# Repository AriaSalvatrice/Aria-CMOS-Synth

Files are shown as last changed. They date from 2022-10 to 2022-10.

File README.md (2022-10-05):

# Aria Salvatrice's WIP CMOS Synth

This repository aims to document the Lunetta-style modular CMOS synth I'm building to learn more about electronics. 

Wanna see it in action?

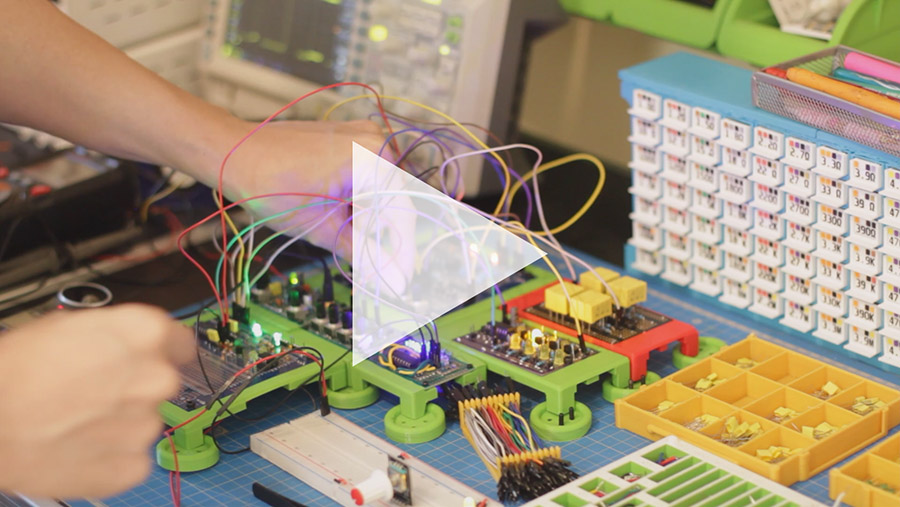
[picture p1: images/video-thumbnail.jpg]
Video Thumbnail (https://youtu.be/UeoF3UkMkqE)


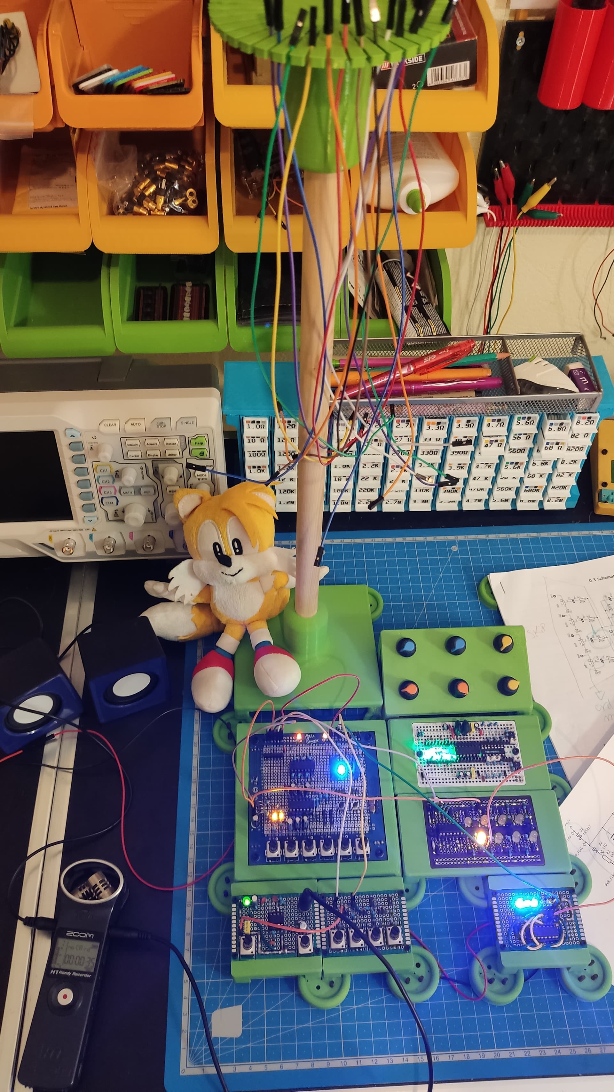
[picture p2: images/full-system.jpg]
Overall view of a system with a few modules


For now, this stuff is only provided publicly to solicit feedback. Depending on the quality of the completed synth and community interest, maybe I'll turn it into a proper open hardware project fit for human consumption one day. But for now, nobody should reproduce those builds, nor even attempt to learn something from them. I literally didn't know how to make a LED emit light rather than smoke at the start of 2022. I have no clue what I'm doing.

Software you need to open the source files I'm sharing:
- Schematics use [KiCad](https://www.kicad.org/) 6.99+
- Layouts use [DIY Layout Creator](http://diy-fever.com/software/diylc/)
- 3D prints use [FreeCAD](https://www.freecadweb.org/)

Other than this file repository, I document my build process [in a thread on the Look Mum No Computer forum](https://lookmumnocomputer.discourse.group/t/starting-a-little-cmos-synth-build/5375/), post the infrequent video [on my Youtube](https://www.youtube.com/c/AriaSalvatrice), sometimes lurk [/r/synthdiy](https://old.reddit.com/r/synthdiy/), and spam [excessively detailed updates in between the gay shitposts on my personal Tweeter that nobody should follow](https://twitter.com/AriaSalvatrice). 

## About Lunetta and CMOS synths

CMOS synths primarily focus primarily on exploring the interactions of the CMOS 4000 series of chips, which deal with digital logic, signals that are either high or low. Compared to more advanced synth DIY endeavors, they are rather easy to build and understand, cheap to make, and reward experimentation. They are sometimes named after [Stanley Lunetta](http://moosack.net/), who pioneered this style of circuit, and called his work _sound sculptures_. 

Your best introduction to musical applications of CMOS chips would be [Elliot Williams' Logic Noise series](https://hackaday.com/series_of_posts/logic-noise/). To dig deeper, explore over a decade of archives in the [Lunetta forums on electro-music.com](https://electro-music.com/forum/forum-160.html), and read the in-depth circuit analyses of the [Castle Rocktronics](http://castlerocktronics.com/modular.html) modules. 

## Design Goals

Mostly learning electronics for myself, and ending up with a neat little rhythm machine, for now. But it'd be cool if I could eventually turn the best circuits into multiple dedicated PCBs, that you could wire up either with pin headers, or cables going to banana jacks on a panel for a more traditional Lunetta setup.

## Electrical Design

All the guts of the synth are exposed as bare PCBs with male header pins, that the performer patches with female DuPont cables. The small size makes it unsuited for live patching, but exceptionally well suited to experimentation with breadboards.

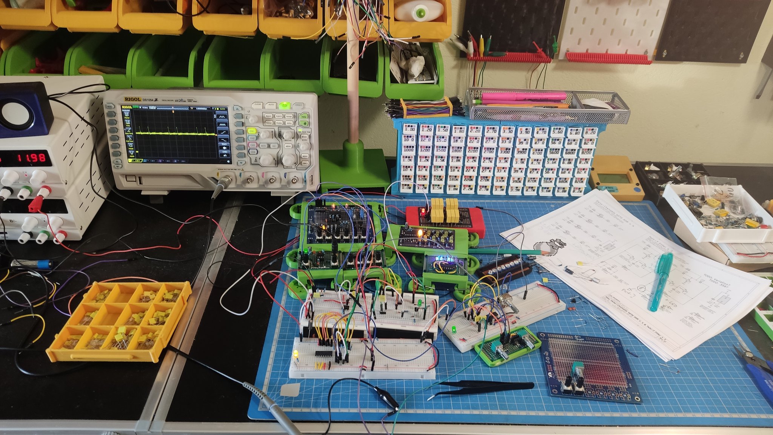
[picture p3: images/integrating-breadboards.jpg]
Extending the system with breadboards


As there are no panels, the aesthetics of the PCBs are important. When performing on video, they must provide a fun and colorful visual spectacle with mucho Blinkenlichten. They must also double as a reasonably ergonomic user interface.

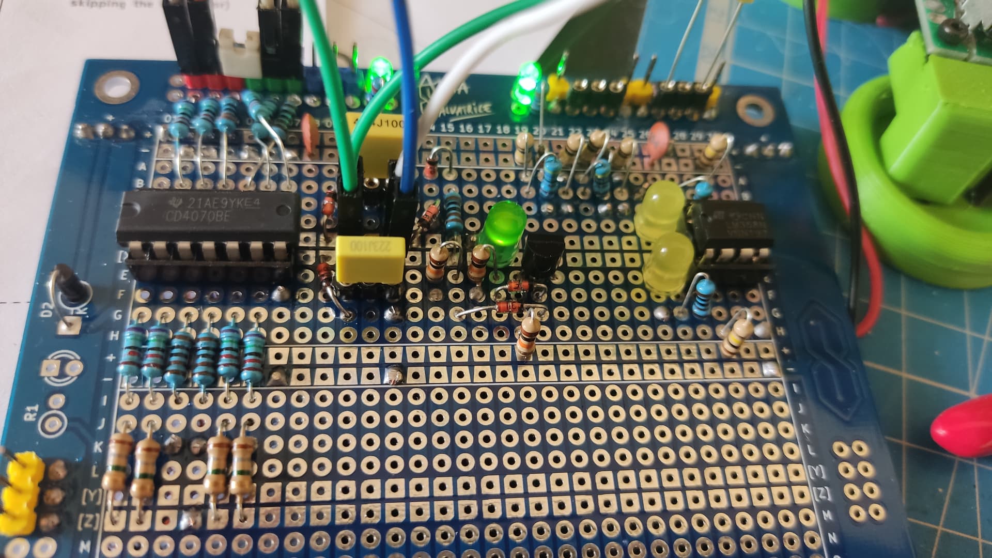
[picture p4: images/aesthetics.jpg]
The aesthetics of the build are important


The system runs on +12V DC. It will also work on +9V, but the values are tuned for +12V, so pitches and envelopes are different at +9V. Some of the circuits I made no longer seem to work at +5V. I picked +12V to make it easier to integrate to a modular synth in the future. There is no dedicated power module yet, it runs off a bench PSU.

To keep the patches readable for the performer, most of the hardwiring is run below the boards. 

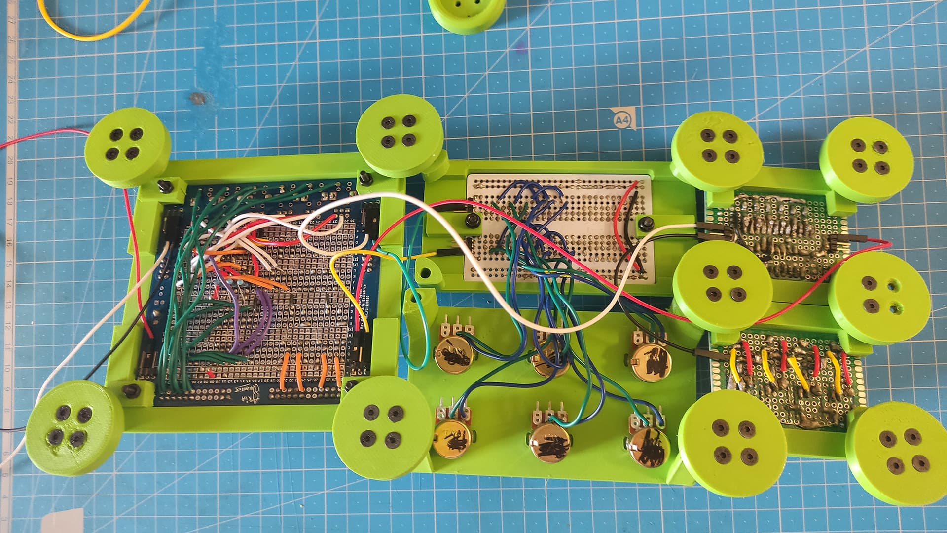
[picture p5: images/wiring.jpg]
Wiring


Most of the circuits used were designed by much more competent people and shared under permissive terms. Individual credits are provided for each module. If you want to learn, learn from the originals, not from my stuff.

## Mechanical Design

The modules are currently printed with PLA. The models were made with FreeCAD. As I don't know FreeCAD well, they are not as easy to modify as I like and can require some post-processing in Blender, the main value of the FreeCAD project is to have a set of measurements that works pretty well. 

The modules tile to an approximate 60×60mm grid. This allows integrating 100×100mm PCBs in 120×120mm modules comfortably, the maximum size for which some PCB fab houses cut you a special deal for minimum quantity orders.

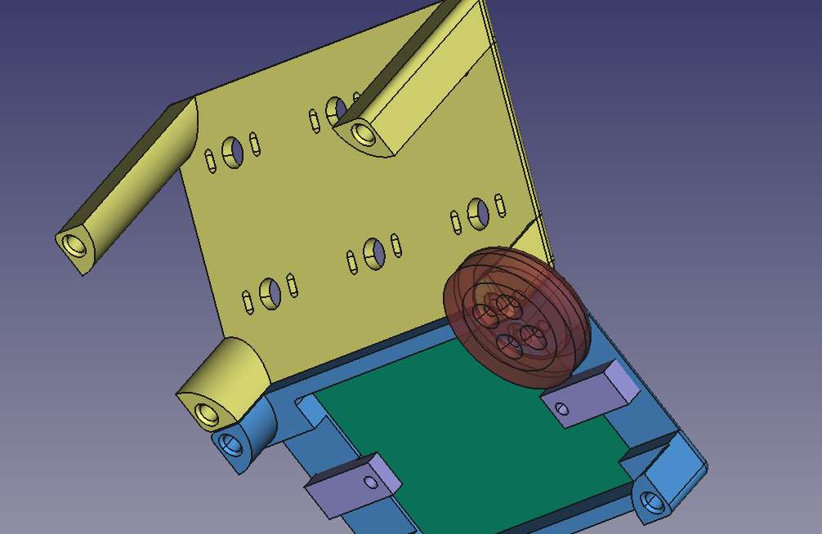
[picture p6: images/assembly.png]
Assembly of modules


The modules are held together by their feet with little holding rings that look like buttons, taking countersunk screws. The holes in the feet of modules are reinforced with heat set inserts.

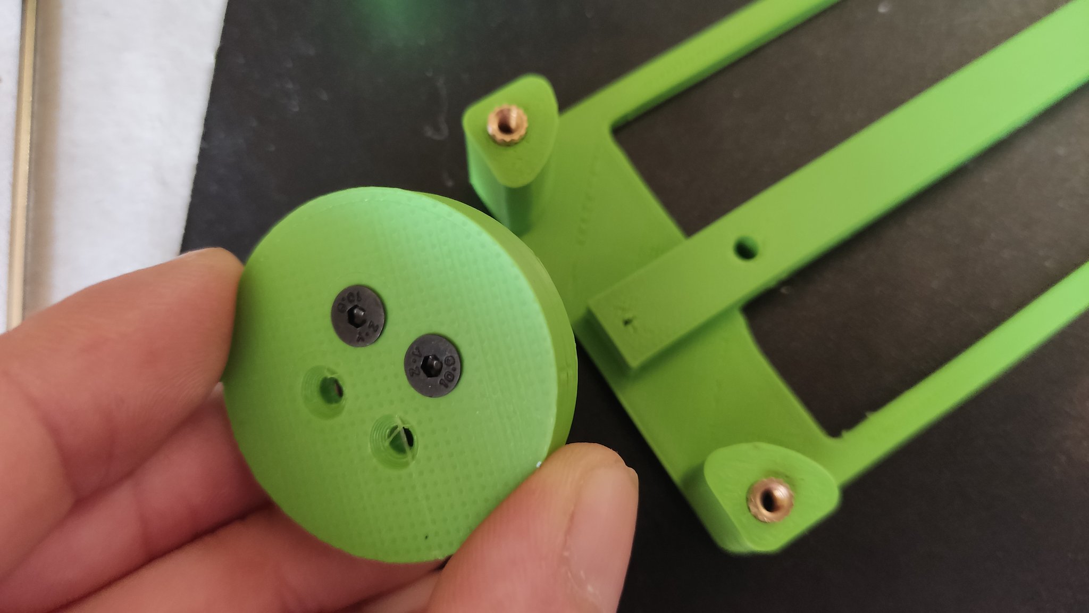
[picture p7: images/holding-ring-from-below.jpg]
Holding ring from below


The models should not require a particularly well tuned printer to make. Most can be printed without supports and don't require much post-processing.

Here's the main measurements (will add more as I confirm them precisely):

| Dimension Name | Value | Comments |
|---|---|---|
| Grid size | 60 × 60 mm 
| Height of modules | 18 mm | Tall enough for vertical headers below the boards, but angled are preferred.
| Spacing between modules | 0.8 mm | Currently, 120×120mm modules don't account for this properly.

## Licensing

lol

-----------

Thanxx for peeping my project. Feel free to look at my learning process, but do not treat my schematics and layouts as instructions yielding an usable product.

Send me thoughts and dog gifs to <woof@aria.dog>.

ttyl,

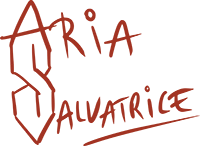
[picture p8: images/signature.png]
Aria Salvatrice


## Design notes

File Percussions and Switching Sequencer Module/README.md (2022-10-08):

Percussions Module & Switching Sequencer Rev1
---------------------------------------------

4 circuits here, meant for my custom prototype board:
- Daisy-chainable XOR. Due to a mistake in the Rev 1 of my protoboard, not all the I/O is at the top, the 4th channel is on the side instead. 
- "Hi-Hat" Envelope with "Choke". Inspired by a circuit [from the Logic Noise series](https://hackaday.com/2015/04/10/logic-noise-more-cmos-cowbell/), just don't ask me how it works, I came up with it through experimentation.
- Gate to Trigger circuit based on Ken Stone's [CGS 24](https://sdiy.info/wiki/CGS_gate_to_trigger_converter). While I got it to work on breadboard, **I couldn't get my final build to work, and didn't manage to diagnose it yet**, so I don't know for sure whether my build or my layout is wrong. 
- Switching sequencer with oscillator, based on [Logic Noise](https://hackaday.com/2015/02/23/logic-noise-the-switching-sequencer/). Uses only 2 gate inputs and 4 pots, but the chip could support 3 and 8.

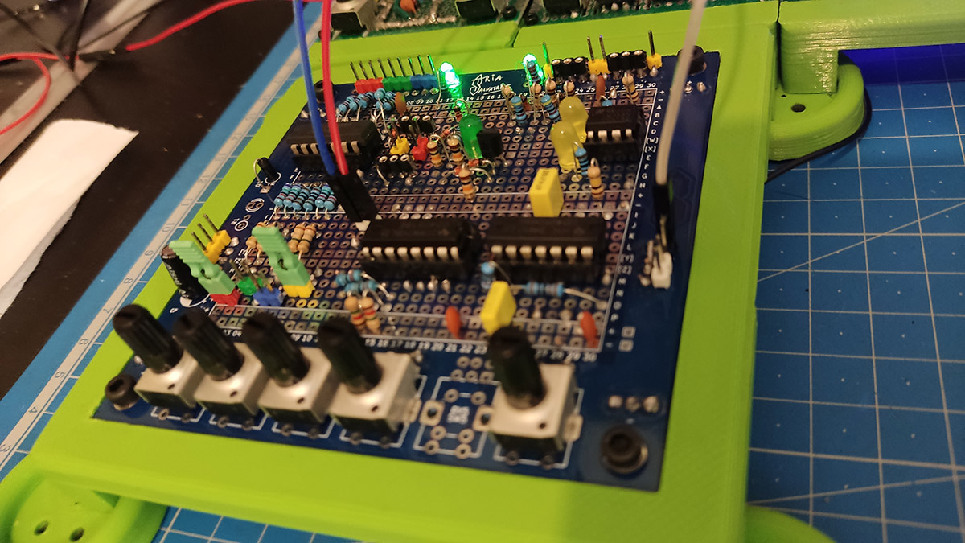
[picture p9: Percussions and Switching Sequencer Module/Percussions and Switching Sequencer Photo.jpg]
Photo of the module


------

_This repository documents my learning process. I advise against building those circuits or learning from them. See the [main README file](../README.md) for more information._

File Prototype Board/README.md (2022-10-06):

Protoboard Rev2B
----------------

Inspired by commercialy available Permanent Prototype boards, and [Analog Output's Protoboard for Eurorack and Kosmo](https://github.com/holmesrichards/Protoboard). It's 99×99 mm, to get the best deal from PCB fab houses.

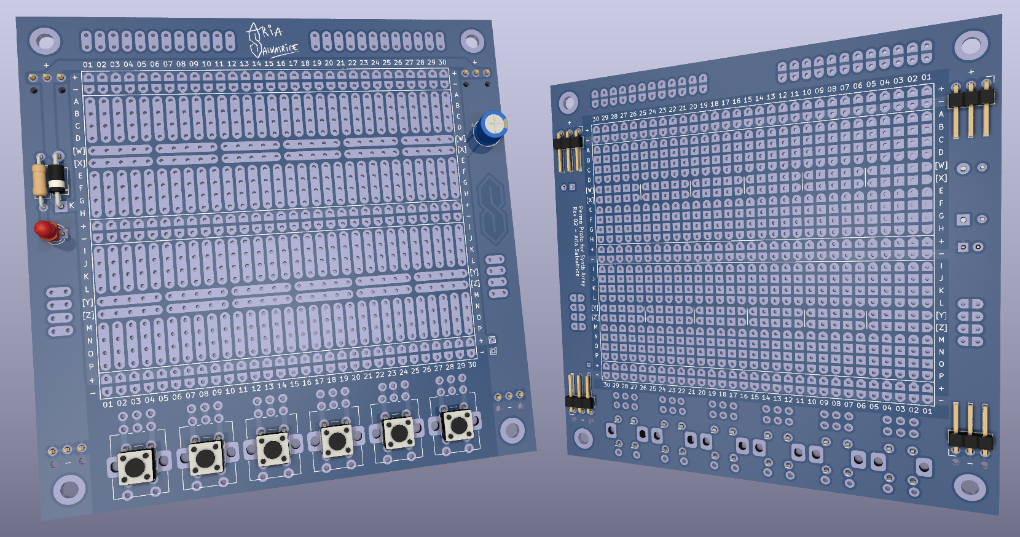
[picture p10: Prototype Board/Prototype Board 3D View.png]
3D view


There's built-in reverse voltage protection, a status LED, a main decoupling capacitor, room for 6 potentiometers or tactile buttons, and two half-breadboard layouts stacked over each other, with power rails.

The footprints at the bottom can be populated with pushbuttons or potentiometers. They are not connected to the rest of the circuit, but the topmost pad of each group can be used to run wires. Bear in mind that potentiometers are mounted with the pins in reverse order.

The 2 groups of 12 pins at the top and 2 groups of 4 pins on the sides are not connected to anything either. Use them creatively, for example for I/O.

The [W], [X], [Y] and [Z] rows are comprised of 6 groups of 5 pads each, which could be useful to run a signal below a chip.

Those boards are for a single rail power supply, limiting their usefulness for most synthesizer projects.

These are the files for Rev2B. Rev2A has been sent to fabricate (will update). Rev2B is the same with a minor correction (misaligned tracks) and has not been tested.

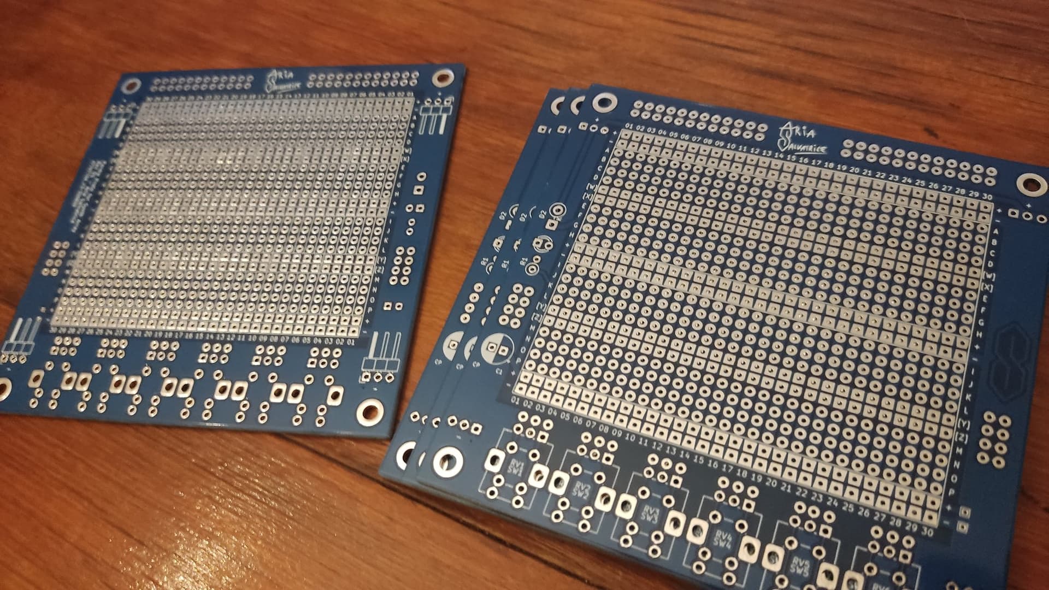
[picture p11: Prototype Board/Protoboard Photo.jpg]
Photo of the module


This is a picture of Rev1, which has a few flaws (such as the status LED shorting if populated). It was my first PCB ever, so I'm happy it even worked at all.

------

_This repository documents my learning process. I advise against building those circuits or learning from them. See the [main README file](../README.md) for more information._

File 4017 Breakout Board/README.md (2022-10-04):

4017 Breakout Board Rev1
------------------------

8-step counter.

[Based on the Logic Noise series](https://hackaday.com/2015/04/24/logic-noise-sequencing-in-silicon/). The article suggests using two 4017 to drive LEDs, but this design uses transistors instead. Seems to work fine. Layout built for a breadboard-style PCB. Harwired reset to limit it to 8 steps, which is more useful in conventional music than the chip's maximum of 10.

This revised layout was not double-checked against the working original build (as I altered the layout a bit on the fly while building).

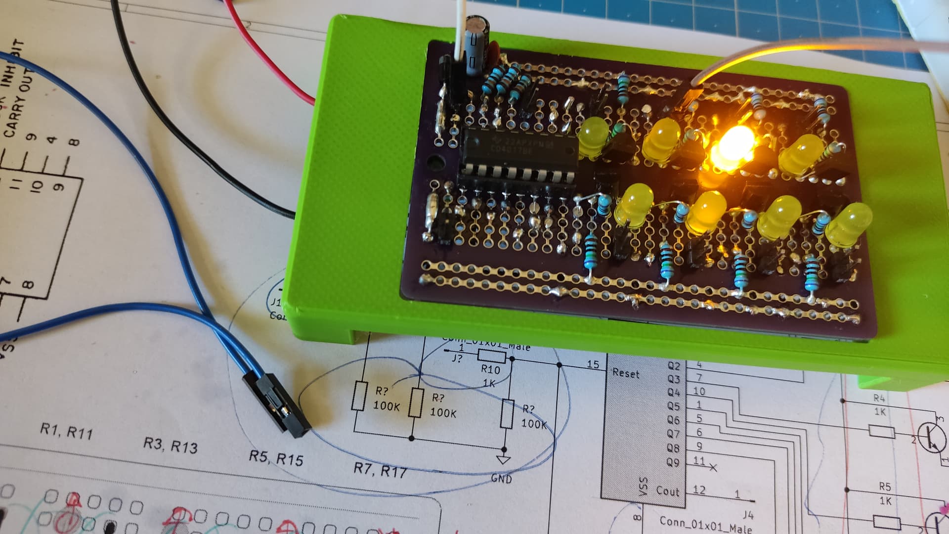
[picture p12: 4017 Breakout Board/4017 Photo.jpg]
Photo of the module


------

_This repository documents my learning process. I advise against building those circuits or learning from them. See the [main README file](../README.md) for more information._

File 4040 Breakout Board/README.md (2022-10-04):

4040 Breakout Board Rev1
------------------------

The 4040 binary counter can be used to divide a clock or to generate sub-oscillators.

[Based on the Logic Noise series](https://hackaday.com/2015/02/17/logic-noise-8-bits-of-glorious-sounds/). Layout meant for a 40×60 mm perfboard. No schematic was made for that one, but it's really simple. It drives LEDs directly, which might be a terrible idea, I have not really checked (it works tho). I routed the cables above the chip, which was a terrible idea. Also, the angled headers do not have sufficient lateral clearance as indicated, I had to bend them to be vertical instead.

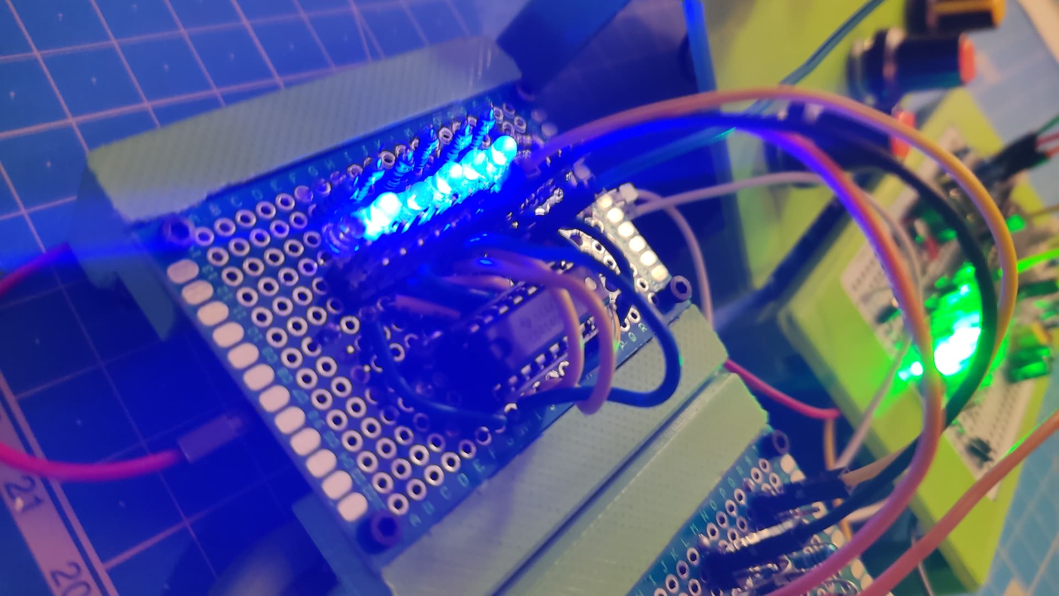
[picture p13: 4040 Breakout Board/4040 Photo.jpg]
Photo of the module


------

_This repository documents my learning process. I advise against building those circuits or learning from them. See the [main README file](../README.md) for more information._

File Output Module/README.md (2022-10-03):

Output Module Rev1
------------------

Based on the [Castle Rocktronics schematics](http://castlerocktronics.com/modular/articles/CR-002_-_Output_Mixer.pdf). Like it's basically a copy-paste at this point. Using a TL072 that is almost certainly not authentic. You'll need to amplify the signal to listen to it comfortably (the original schematics suggest a way to do it, but I haven't bothered).

Built for a 60×40 mm perfboard, drilled to fit a mini-jack, with grooves for the potentiometer routed out using a rotary tool with a cutoff wheel. Wear a respirator while machining a PCB!

I made the mixer separately. Its design has a fatal flaw so I will not bother to document it.

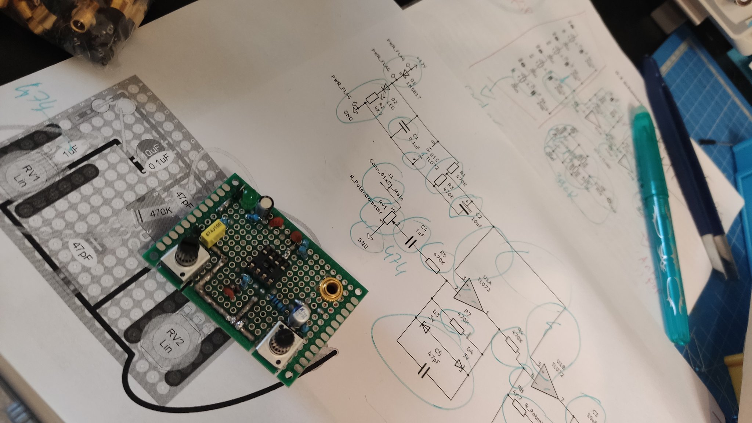
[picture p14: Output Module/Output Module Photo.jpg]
Photo of the module


------

_This repository documents my learning process. I advise against building those circuits or learning from them. See the [main README file](../README.md) for more information._

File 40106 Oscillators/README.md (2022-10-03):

40106 Oscillators Rev2
----------------------

Six voltage-controlled oscillators, 2 LFO, 2 in the lower audio range, and 2 in the higher audio range. Square and triangle wave outputs. 

This build is meant to use my Perma-Proto PCBs Rev1. 

The oscillators are [based on the Logic Noise series](https://hackaday.com/2015/03/09/logic-noise-sawing-away-with-analog-waveforms/). The [schematics from Castle Rocktronics were also used](http://castlerocktronics.com/modular/articles/CR-001_-_4xSQUARE.pdf). It's worth noting that when using all inverters on a 40106, they will have a fairly noticeable amount of cross-talk.

To fill the space, there are also passive mults, LDRs, pushbuttons, and a pair of vactrol LPG, I cribbed [the schematics from Mystic Circuits](https://github.com/mysticcircuits/0HP_Modular/tree/master/Hardware/0HP%20Vactrol%20LPG-VCA). The vactrols are handmade with a LDR and a LED in heat shrink tubing. They need decent current to work, not everything in my system manages to ping them properly, so I wanna remake that part better later.

While the Rev Log pots specified will yield better results, I used Linear, not having anything else in stock.

I made a Rev 1 of it previously, but it's too flawed to bother documenting.

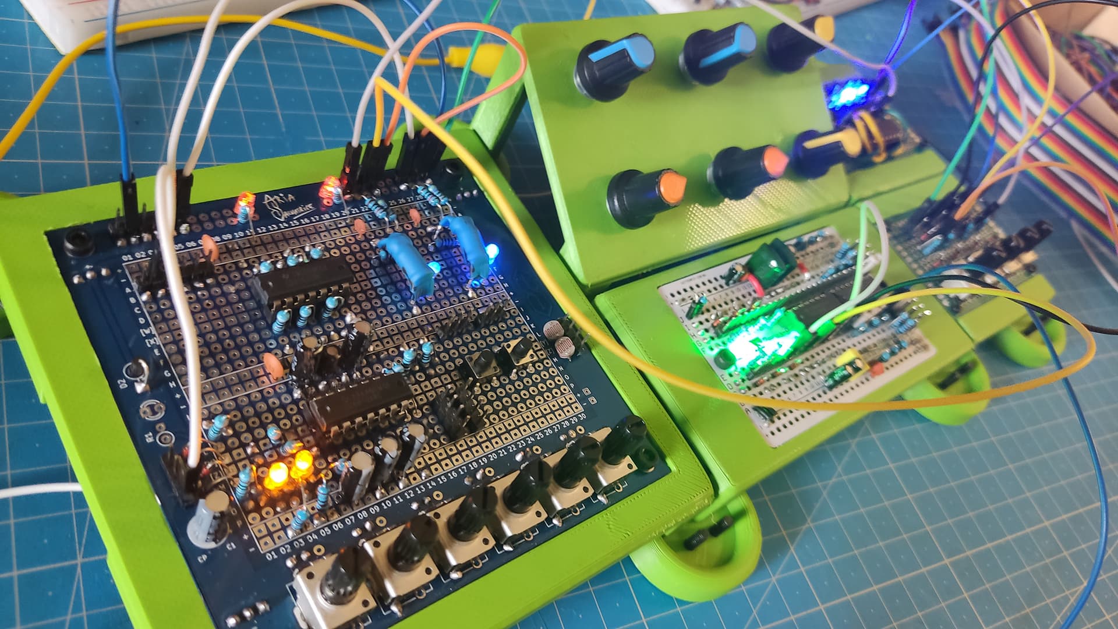
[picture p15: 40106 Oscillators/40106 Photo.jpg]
Photo of the module
    
Rev 2 on the left, Rev 1 immediately to its right.

------

_This repository documents my learning process. I advise against building those circuits or learning from them. See the [main README file](../README.md) for more information._

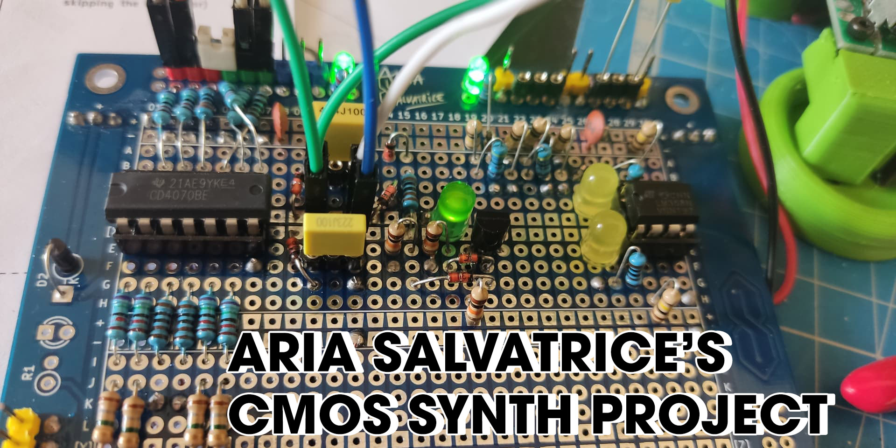
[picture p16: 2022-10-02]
images/header.jpg

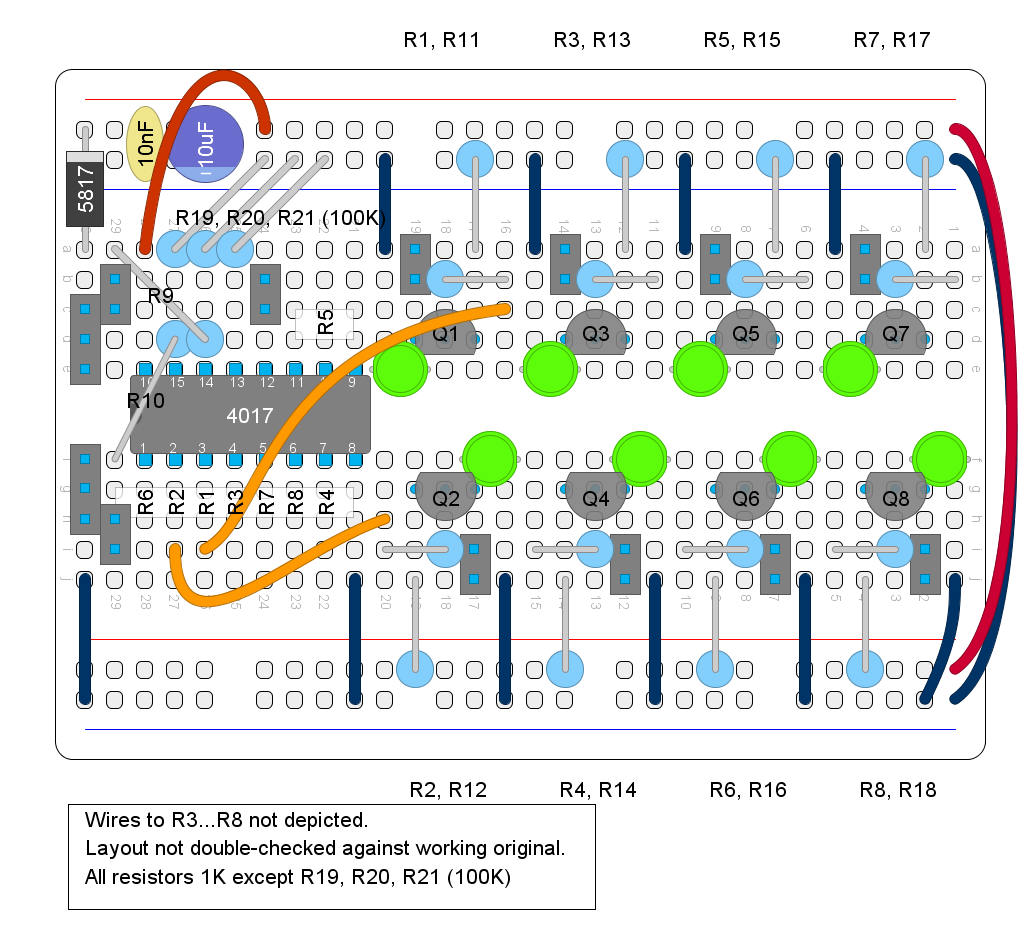
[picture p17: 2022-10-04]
4017 Breakout Board/4017 Layout.png

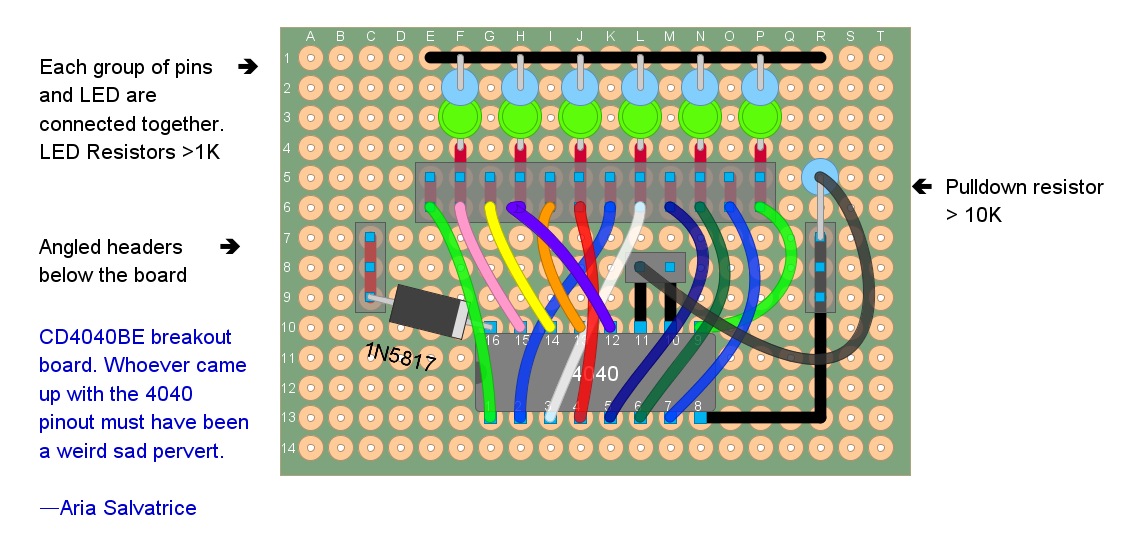
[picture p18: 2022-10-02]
4040 Breakout Board/4040 Layout.png

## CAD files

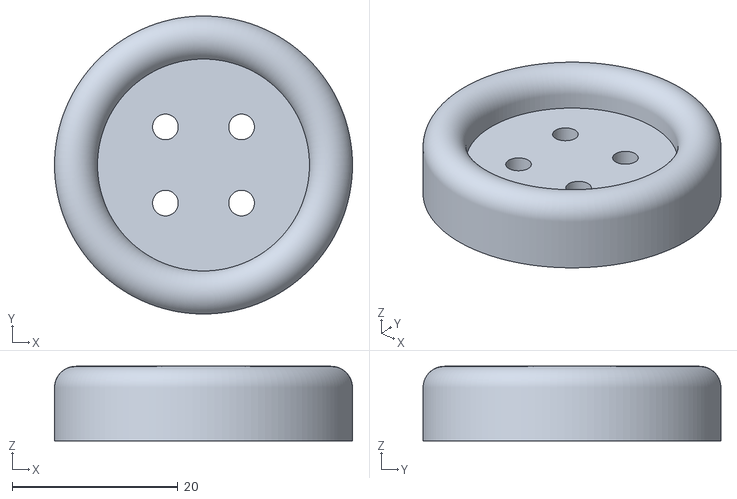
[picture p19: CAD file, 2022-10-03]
3D Prints/stl/Holding Ring.stl
36.0 x 36.0 x 9.00

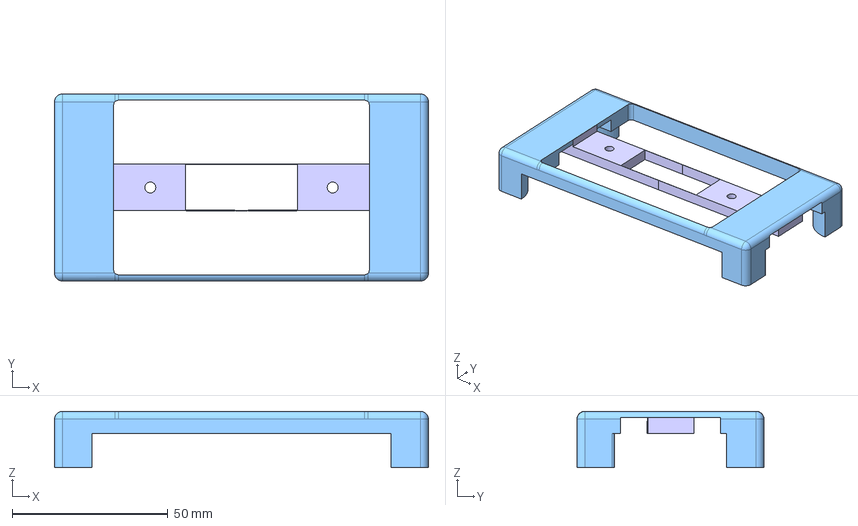
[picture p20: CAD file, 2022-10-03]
3D Prints/Synth Support System.FCStd
120.0 x 60.0 x 18.0 mm
Box Holder Center Holes L
Box Holder Center Hole R

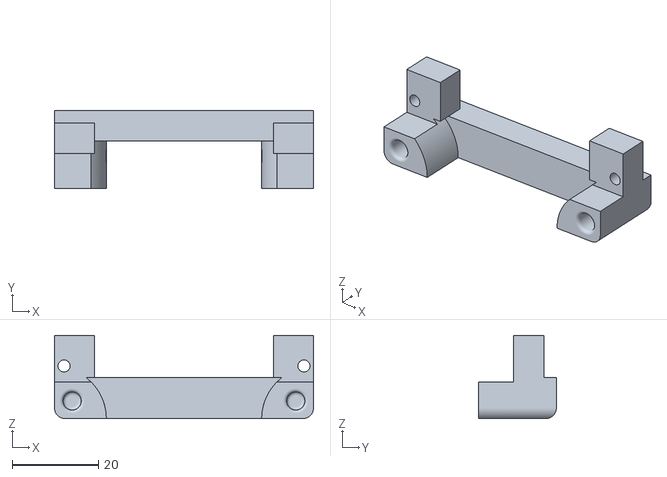
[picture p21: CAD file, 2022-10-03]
3D Prints/stl/Support - 40x60 perfboard - single support.stl
60.0 x 18.0 x 19.3

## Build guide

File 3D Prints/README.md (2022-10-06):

3D Prints
---------
The system tiles pretty well, but can use a tiny bit of postprocessing help: a heat gun, 3D pen, and deburring tool can help obtain a better fit.

The feet of supports require M3 heat set inserts. A soldering iron is required to install them, only use an old tip you don't mind ruining.

Adding the rest of the files as I double-check the versions, dimensions, and make test prints.

### `Synth Support System.FCStd`

A messy and exploratory file, as I don't know FreeCAD much yet. Still, might be useful to make variations, try out changing dimensions in the spreadsheet and see if it works. Be ready to double-check dimensions and post-process models in Blender if you use it.

### `./stl/Holding Ring.stl`

Hold feet together. Takes countersunk M3×12mm screws.

### `./stl/Support - 60x40 perfboard - single support.stl`

[UNVERIFIED MODEL] Print two per 40×60 mm perfboard. In the default orientation, where it is printed on its side, it requires no supports. 

For a smoother surface finish, it can alternatively be printed upside-down with small painted-on supports at the edge of PCB holder, as follows:

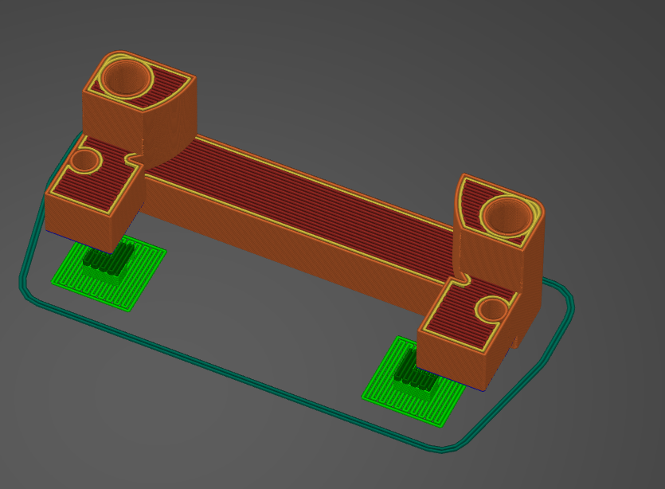
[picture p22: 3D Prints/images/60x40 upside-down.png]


Secure boards with M2x12 screws and nuts. Note that two contiguous perfboards will almost touch, pads to their sides might be at risk of shorting if used.

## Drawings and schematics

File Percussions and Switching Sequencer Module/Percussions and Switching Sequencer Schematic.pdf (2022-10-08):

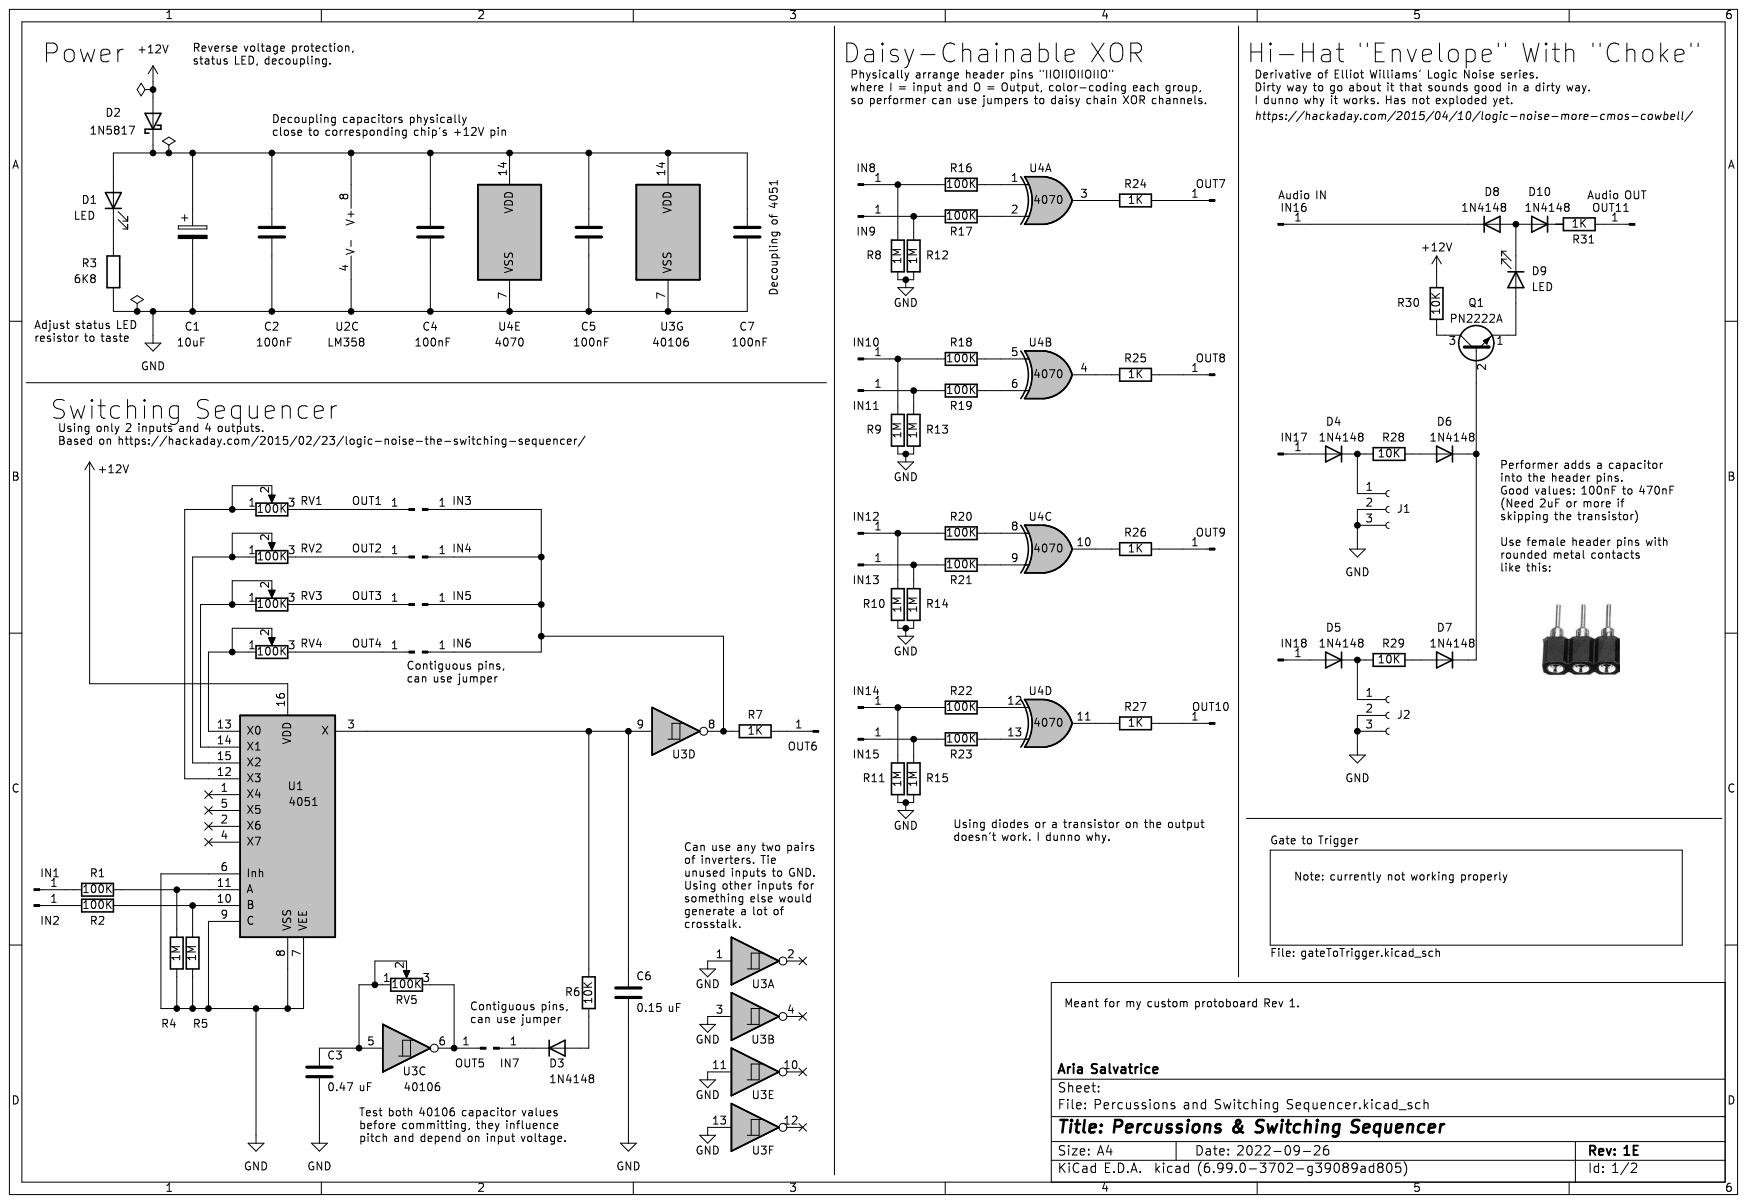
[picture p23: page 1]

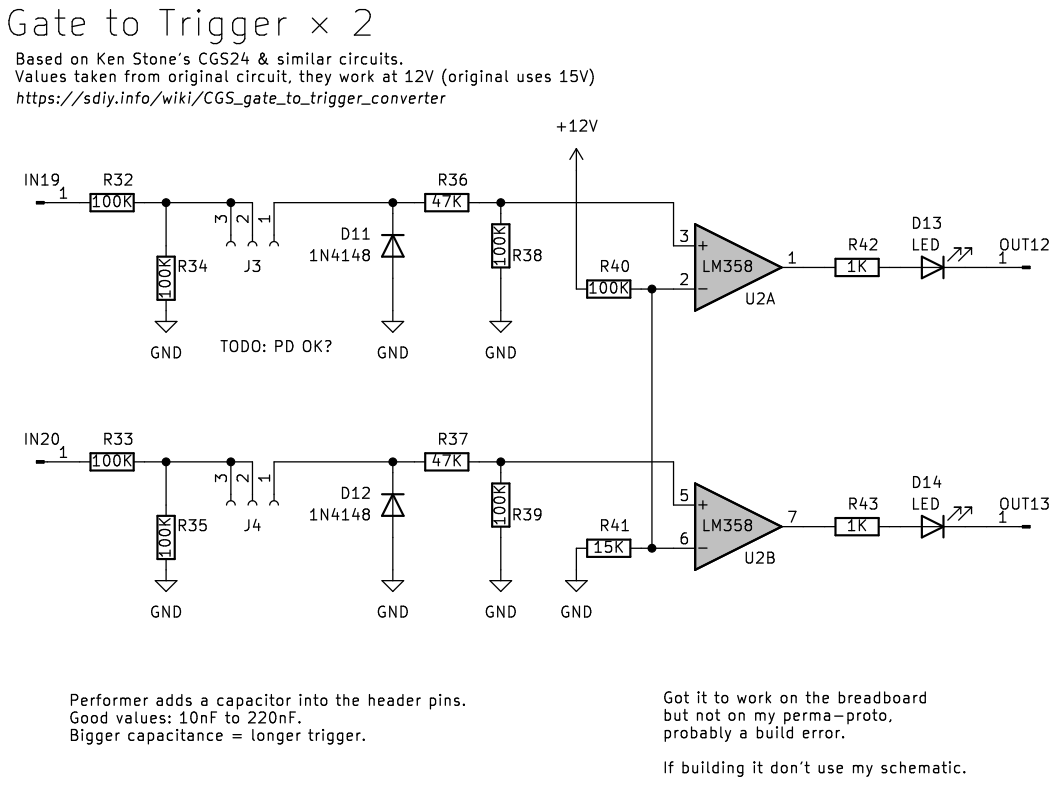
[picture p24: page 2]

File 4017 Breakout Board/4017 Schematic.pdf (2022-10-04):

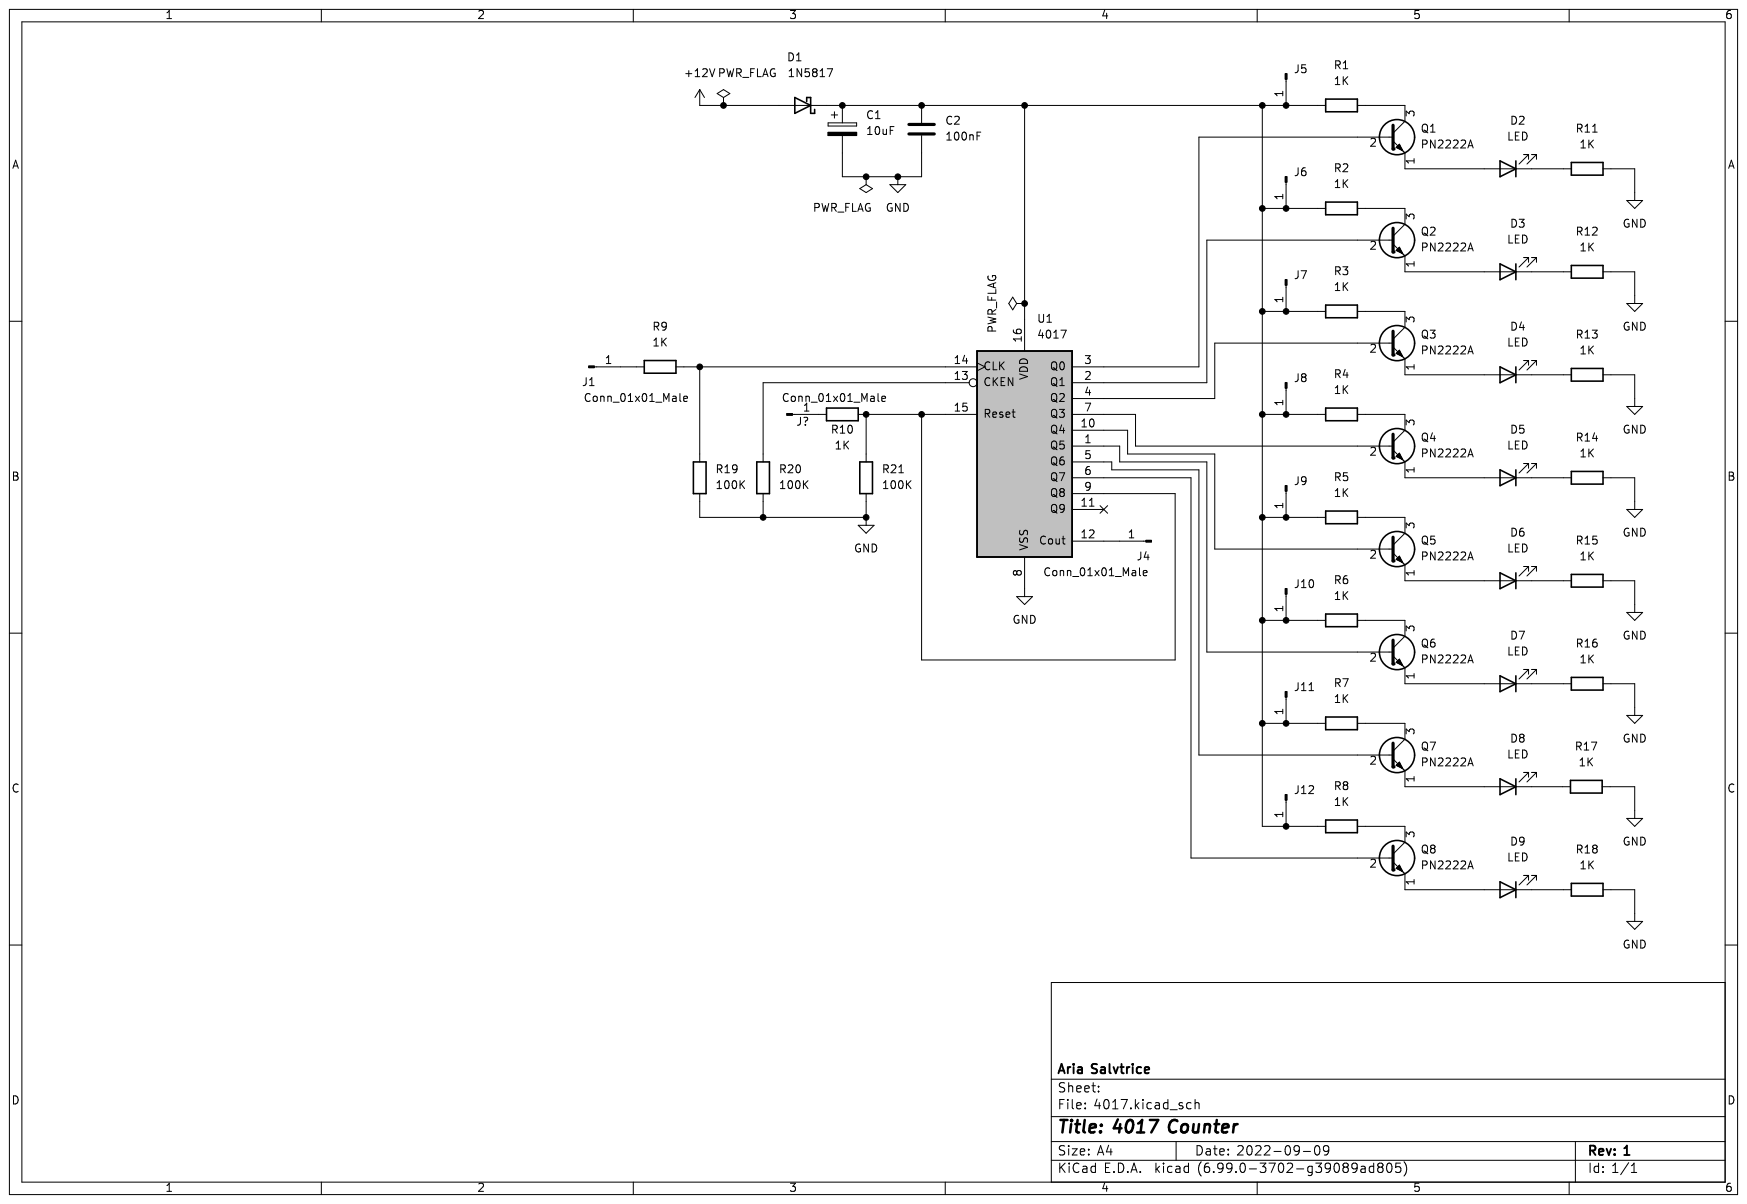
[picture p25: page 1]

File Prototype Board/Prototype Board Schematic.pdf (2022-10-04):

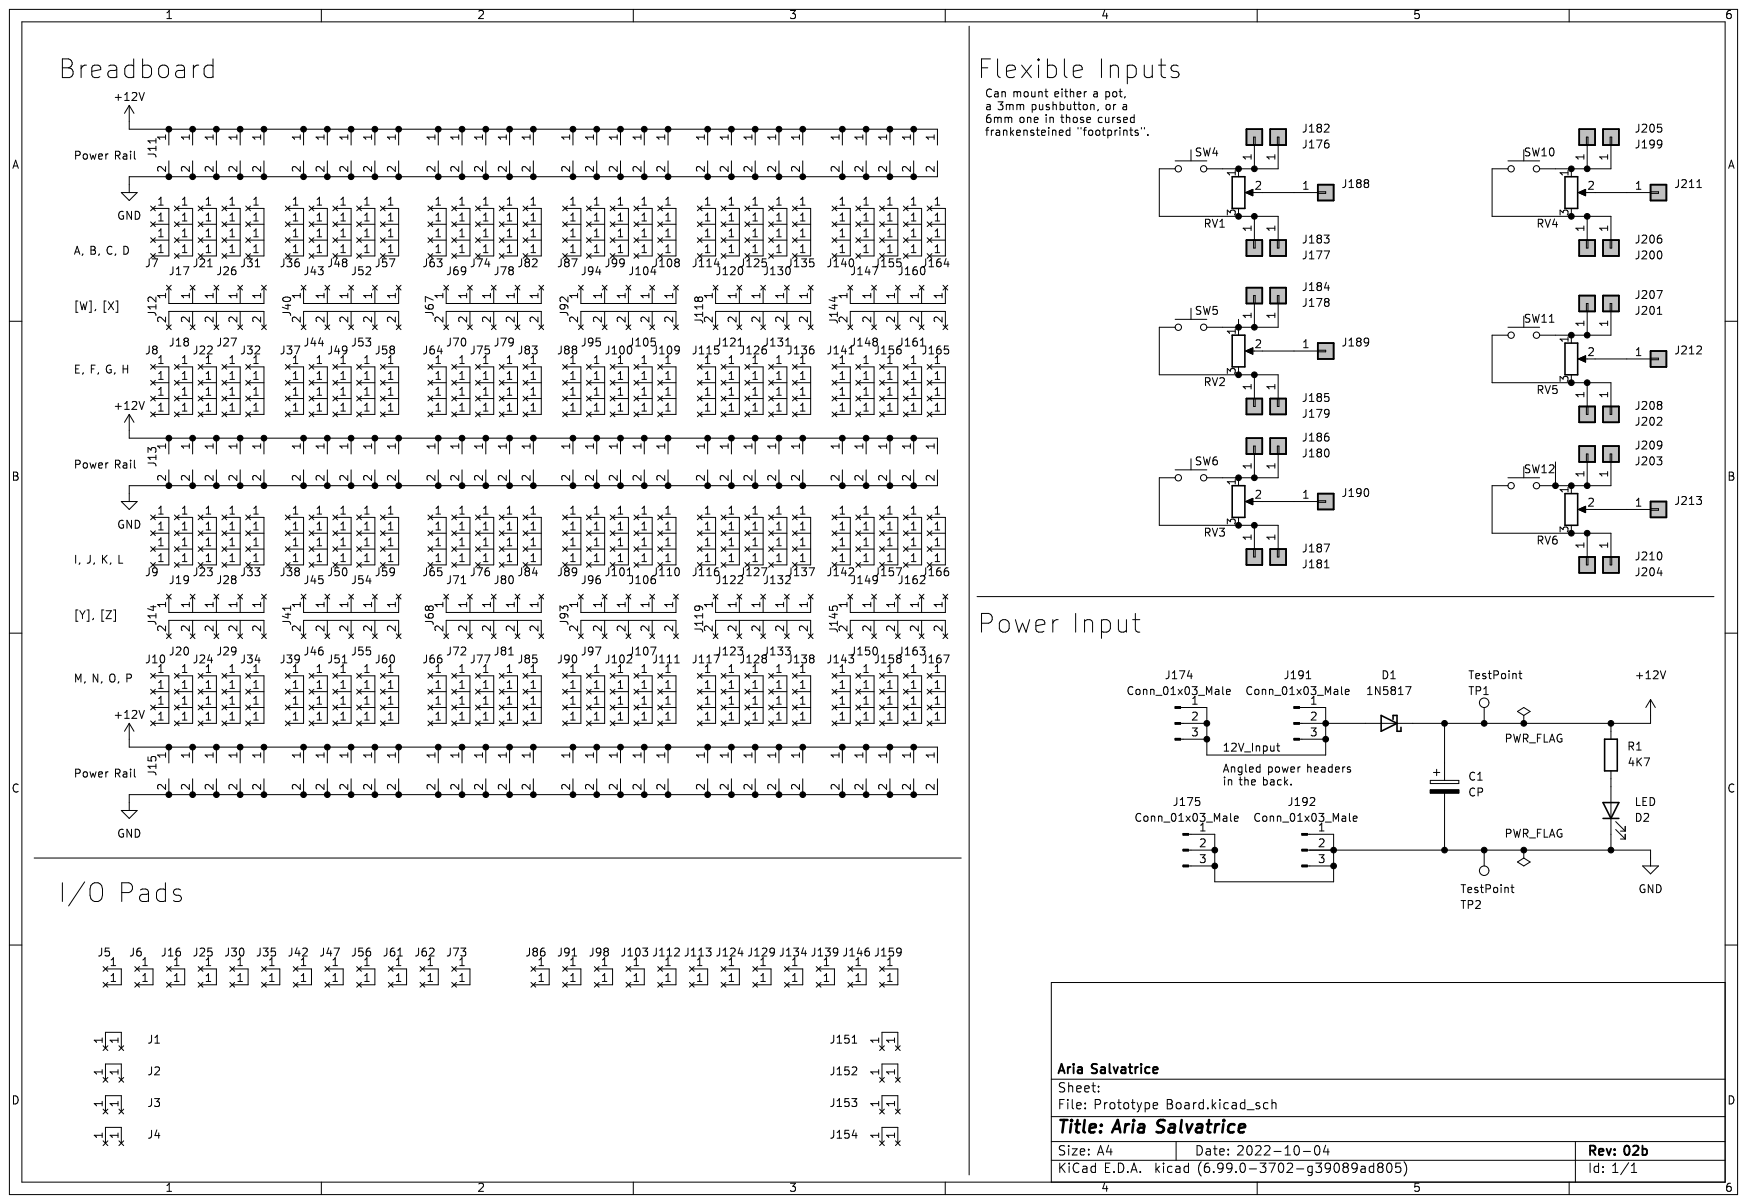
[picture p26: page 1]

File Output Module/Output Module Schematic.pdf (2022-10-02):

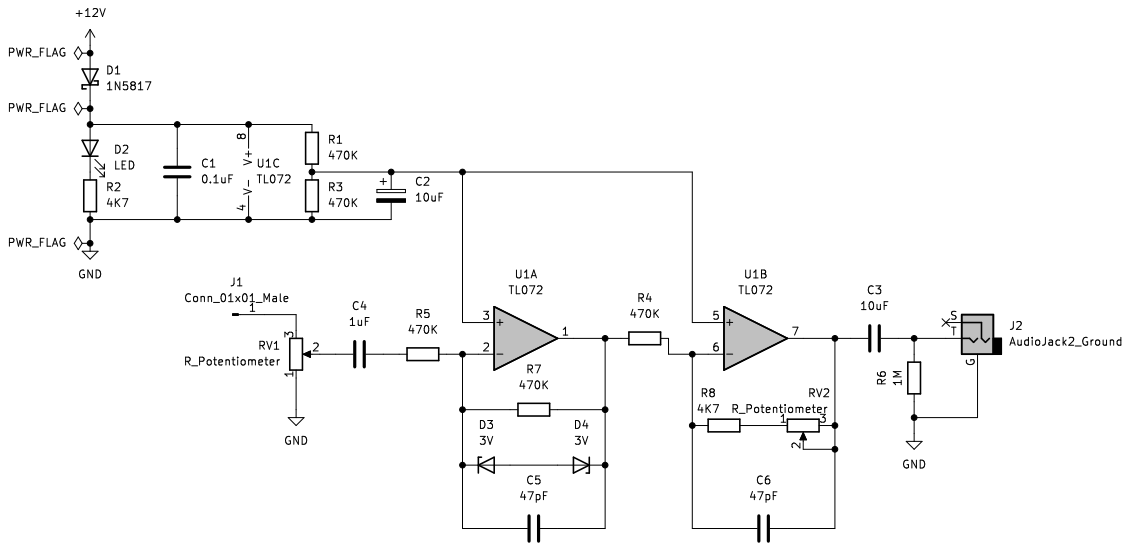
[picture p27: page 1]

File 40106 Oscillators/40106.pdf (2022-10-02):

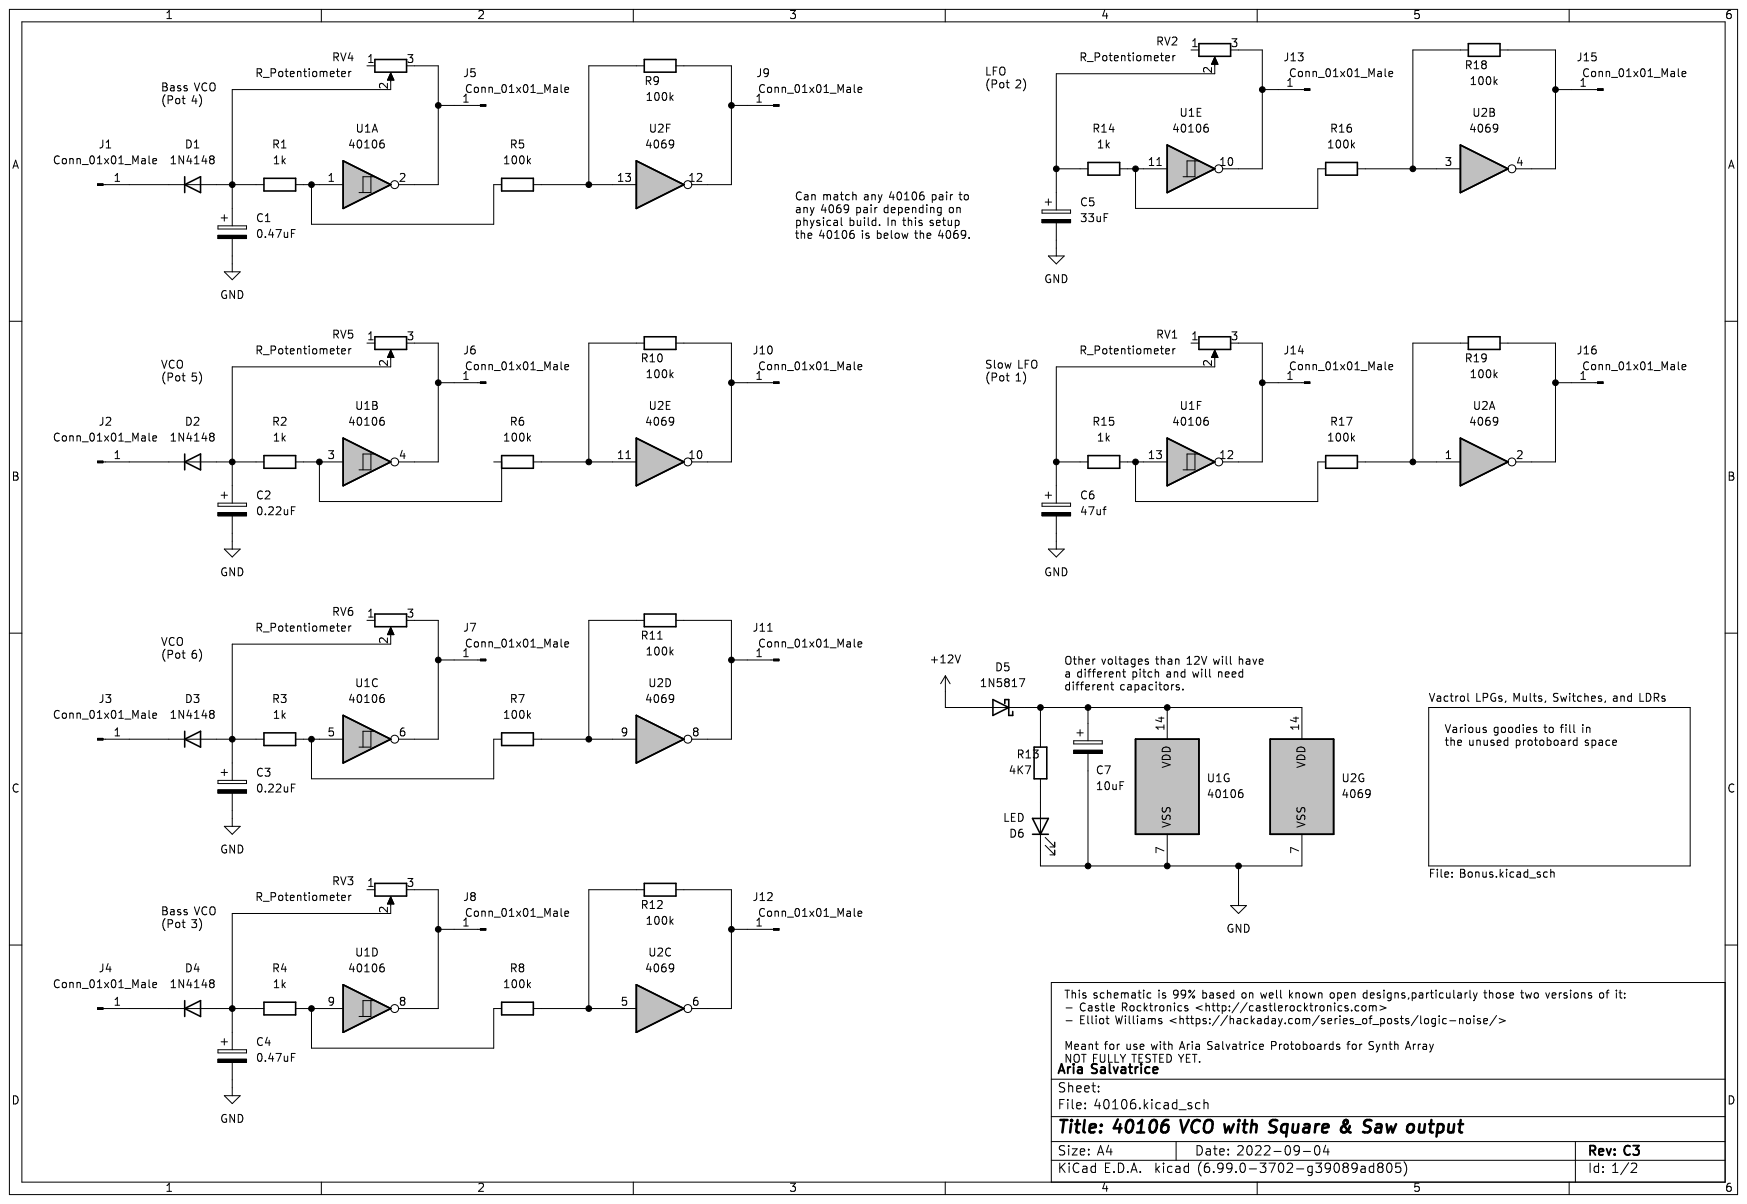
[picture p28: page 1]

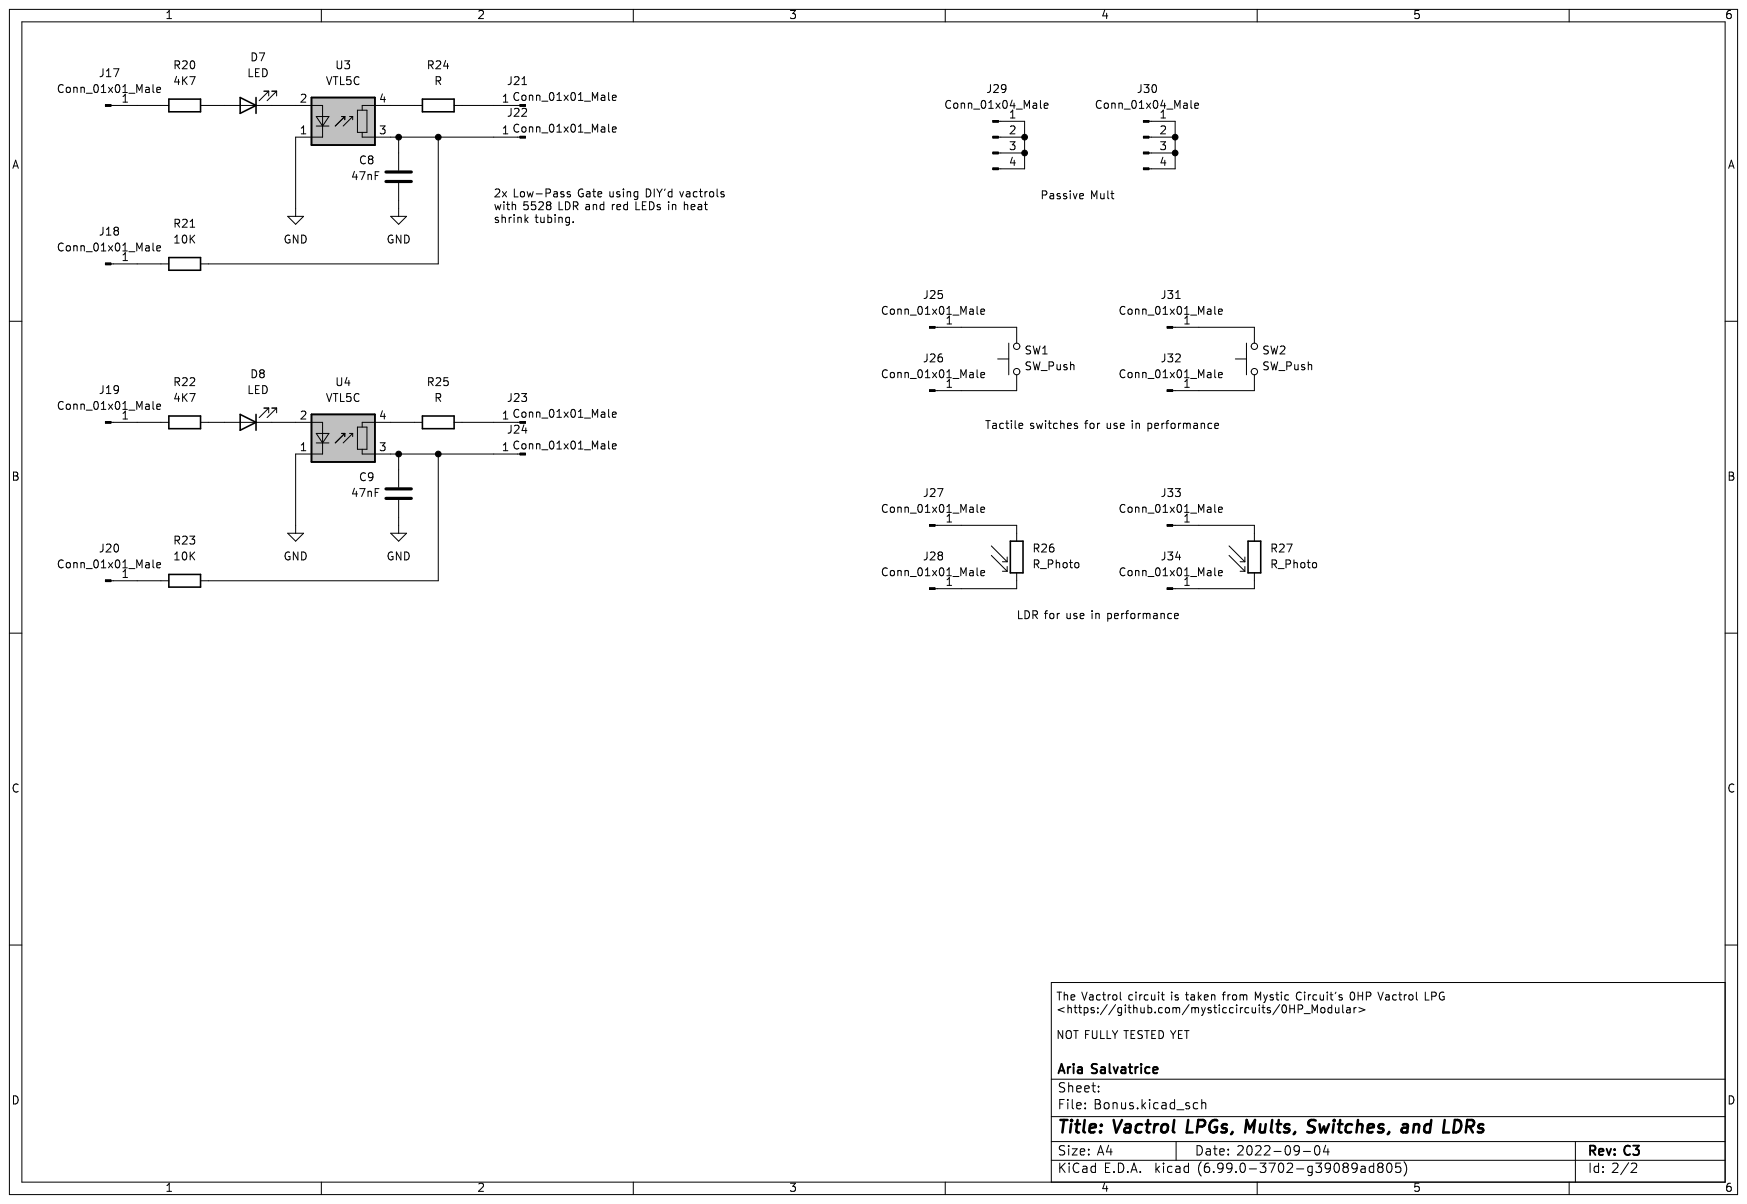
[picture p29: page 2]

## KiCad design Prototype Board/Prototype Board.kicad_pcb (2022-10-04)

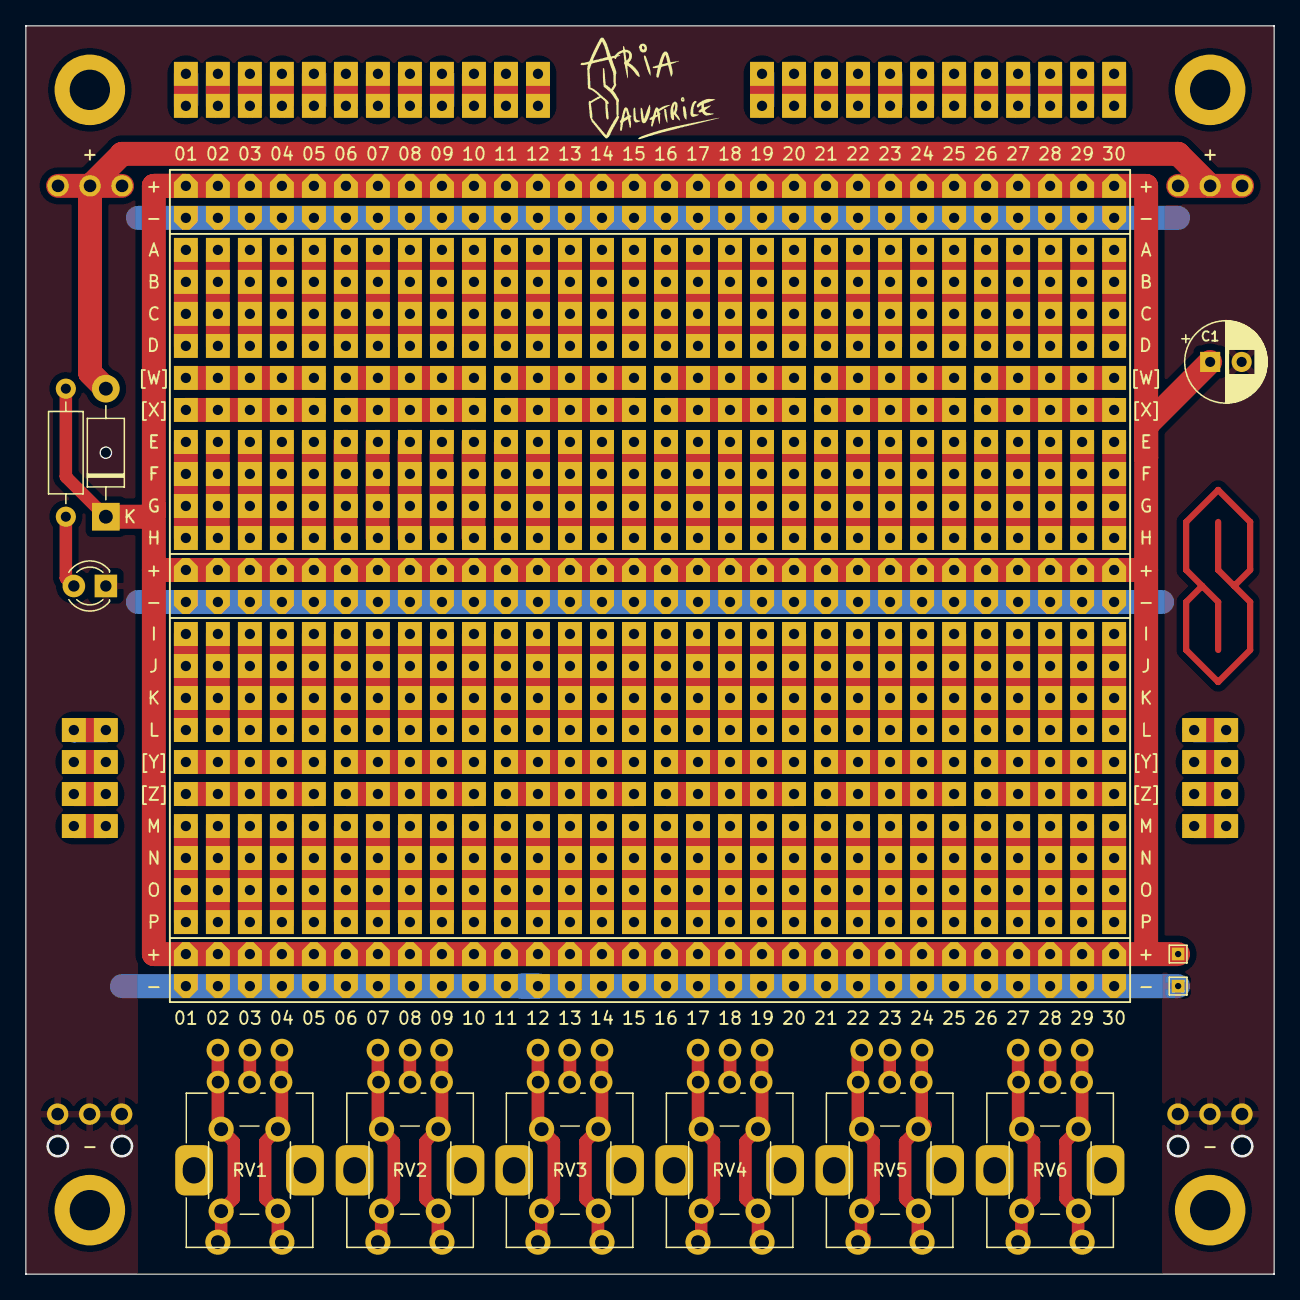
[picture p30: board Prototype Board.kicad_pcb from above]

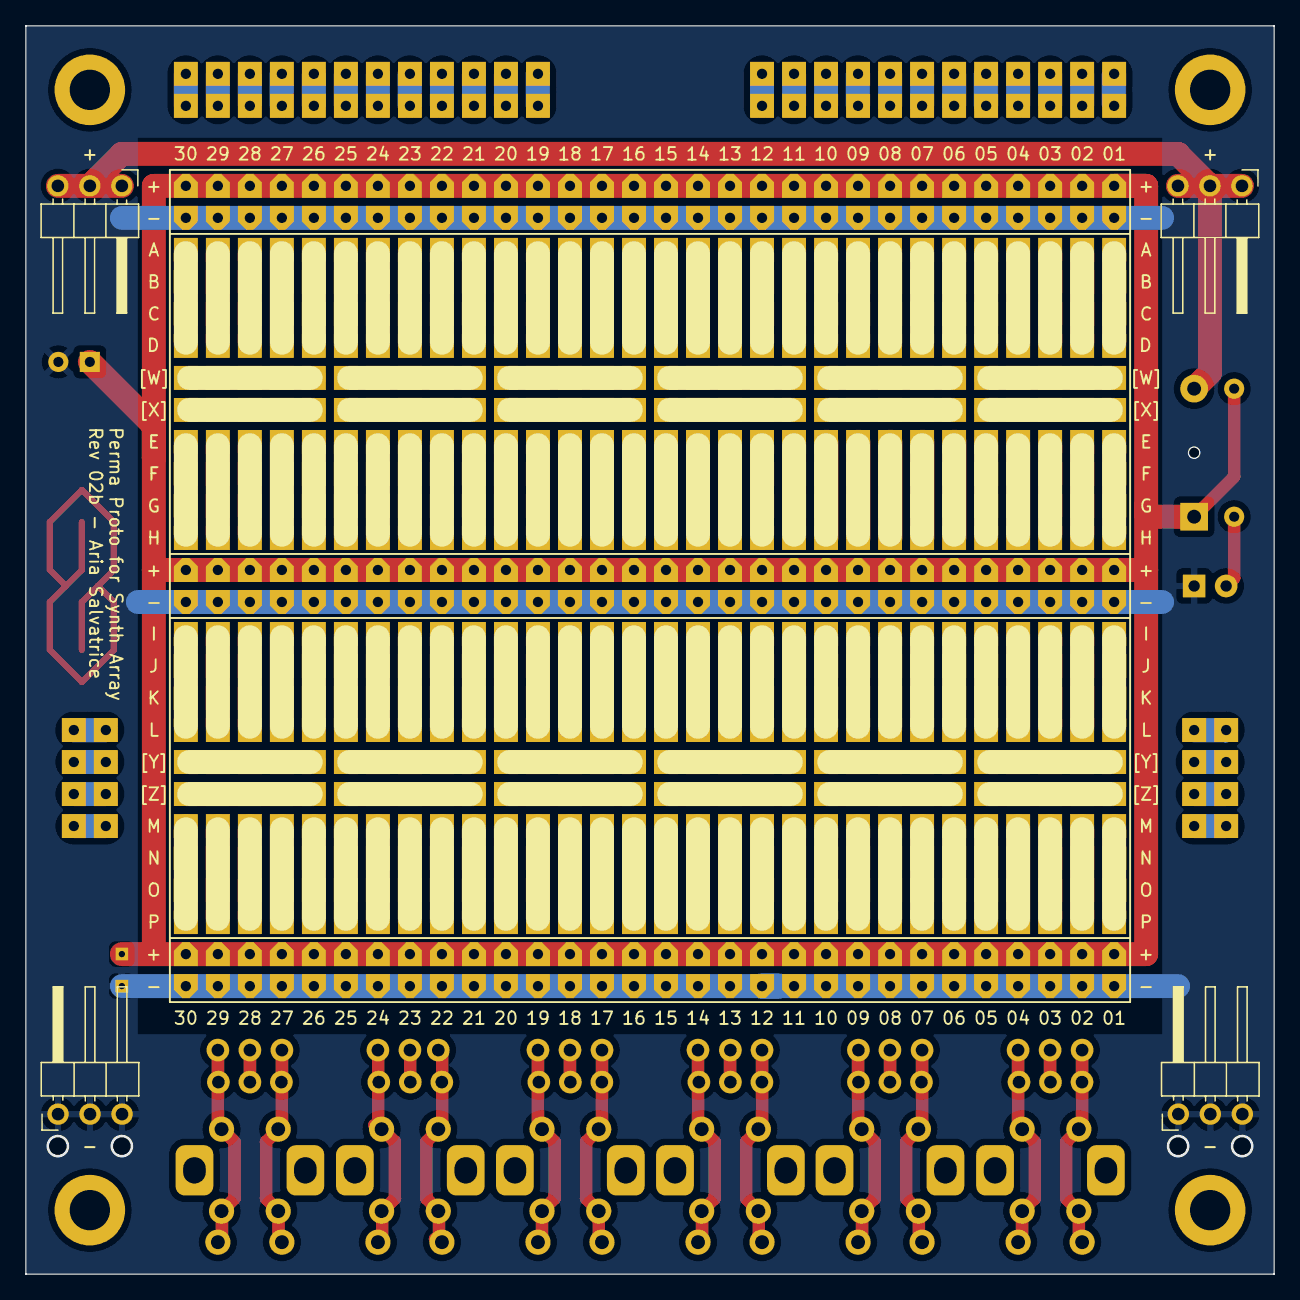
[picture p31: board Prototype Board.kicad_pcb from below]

Board: 2 copper layers, 99.1 x 99.1 mm, 219 parts (4 on the bottom side), 22 nets.

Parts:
C1: CP; CP_Radial_D6.3mm_P2.50mm
D1: 1N5817; D_DO-41_SOD81_P10.16mm_Horizontal
D2: LED; LED_D3.0mm
J1, J2, J3, J4, J5, J6, J16, J25, J30, J35, J42, J47, J56, J61, J62, J73, J86, J91, J98, J103, J112, J113, J124, J129, J134, J139, J146, J151, J152, J153, J154, J159: Connectable_Pad_Group_01x02
J7, J8, J9, J10, J17, J18, J19, J20, J21, J22, J23, J24, J26, J27, J28, J29, J31, J32, J33, J34, J36, J37, J38, J39, J43, J44, J45, J46, J48, J49, J50, J51, J52, J53, J54, J55, J57, J58, J59, J60, J63, J64, J65, J66, J69, J70, J71, J72, J74, J75, J76, J77, J78, J79, J80, J81, J82, J83, J84, J85, J87, J88, J89, J90, J94, J95, J96, J97, J99, J100, J101, J102, J104, J105, J106, J107, J108, J109, J110, J111, J114, J115, J116, J117, J120, J121, J122, J123, J125, J126, J127, J128, J130, J131, J132, J133, J135, J136, J137, J138, J140, J141, J142, J143, J147, J148, J149, J150, J155, J156, J157, J158, J160, J161, J162, J163, J164, J165, J166, J167: Connectable_Pad_Group_01x04
J11, J13, J15: Power_Rail_30
J12, J14, J40, J41, J67, J68, J92, J93, J118, J119, J144, J145: Connectable_Pad_Group_02x05
J174, J175, J191, J192: Conn_01x03_Male; PinHeader_1x03_P2.54mm_Horizontal
J176, J177, J178, J179, J180, J181, J182, J183, J184, J185, J186, J187, J188, J189, J190, J199, J200, J201, J202, J203, J204, J205, J206, J207, J208, J209, J210, J211, J212, J213: Conn_01x01; Perf_Board_Hole
R1: 4K7; R_Axial_DIN0207_L6.3mm_D2.5mm_P10.16mm_Horizontal
RV1, RV2, RV3, RV4, RV5, RV6: R_Potentiometer_MountingPin; Potentiometer_Alps_RK09K_Single_Vertical
SW4, SW5, SW6, SW10, SW11, SW12: SW_Push_Dual; SW_PUSH_6mm
TP1, TP2: TestPoint; TestPoint_THTPad_1.0x1.0mm_Drill0.5mm

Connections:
+12V: C1.1, D1.1 (K), J11.1, J13.1, J15.1, R1.2, TP1.1
/12V_Input: D1.2 (A), J174.1, J174.2, J174.3, J191.1, J191.2, J191.3
GND: C1.2, D2.1 (K), J11.2, J13.2, J15.2, J175.1, J175.2, J175.3, J192.1, J192.2, J192.3, TP2.1
unnamed: D2.2 (A), R1.1
unnamed: J176.1, J182.1, RV1.1, SW4.2
unnamed: J177.1, J183.1, RV1.3, SW4.1
unnamed: J178.1, J184.1, RV2.1, SW5.2
unnamed: J179.1, J185.1, RV2.3, SW5.1
unnamed: J180.1, J186.1, RV3.1, SW6.2
unnamed: J181.1, J187.1, RV3.3, SW6.1
unnamed: J188.1, RV1.2
unnamed: J189.1, RV2.2
unnamed: J190.1, RV3.2
unnamed: J199.1, J205.1, RV4.1, SW10.2
unnamed: J200.1, J206.1, RV4.3, SW10.1
unnamed: J201.1, J207.1, RV5.1, SW11.2
unnamed: J202.1, J208.1, RV5.3, SW11.1
unnamed: J203.1, J209.1, RV6.1, SW12.2
unnamed: J204.1, J210.1, RV6.3, SW12.1
unnamed: J211.1, RV4.2
unnamed: J212.1, RV5.2
unnamed: J213.1, RV6.2

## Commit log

2022-10-02 Add 4017 board files
    [4017.kicad_sch]
2022-10-02 +4040 Breakout Board
2022-10-02 + 40106 Board
    [40106.kicad_sch, Bonus.kicad_sch]
2022-10-02 + Output Module
    [Output Module.kicad_sch]
2022-10-02 + Percussion board
    [Percussions.kicad_sch]
2022-10-02 PDF of Percussions board schematic
2022-10-03 Adding a few 3D prints
    [Holding Ring.stl, Support - 40x60 perfboard - single support.stl, Synth Support System.FCStd]
2022-10-03 Move images folder, print readme edit
2022-10-03 Add *.kicad_prl to gitignore
2022-10-03 Remove revision from folders
    [40106.kicad_sch, 4017.kicad_sch, Bonus.kicad_sch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]
2022-10-03 Add Protoboard project
    [Breadboard.kicad_sch, PowerRails.kicad_sch, Prototype Board.kicad_pcb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]
2022-10-03 Protoboard edits
    [Prototype Board.kicad_pcb]
2022-10-03 Improve Protoboard Rev2
    [Prototype Board.kicad_pcb, Prototype Board.kicad_sch]
2022-10-03 Protoboard Rev2 ready soon, needs checking
    [PowerRails.kicad_sch, Prototype Board.kicad_pcb, Prototype Board.kicad_sch]
2022-10-03 Proto silkscreen adjust, gitignore gerbers
    [Prototype Board.kicad_pcb]
2022-10-04 Standardize prototype board folder name, Rev 2B
    [Breadboard.kicad_sch, PowerRails.kicad_sch, Prototype Board.kicad_pcb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]
2022-10-04 Fix 4017 layout + Speling's
    [4017.kicad_sch]
2022-10-05 Remove Rev1 from folder name
    [Percussions.kicad_sch]
2022-10-08 Try out switching sequencer
    [Percussions.kicad_sch]
2022-10-08 Percussions add switching sequencer
    [Percussions.kicad_sch]
2022-10-08 Add switching sequencer to module
    [Percussions and Switching Sequencer.kicad_sch, gateToTrigger.kicad_sch]
